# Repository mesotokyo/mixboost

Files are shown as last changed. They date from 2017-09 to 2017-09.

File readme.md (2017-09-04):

# MixBoost - Clean Booster & Loop Switcher & Send-Return mixer stompbox effector



## toggle mode by SW2

 * When SW2 is upper position, 'latch mode' - toggle ON/OFF by push SW1.
 * When SW2 is lower position, 'momentary mode' - ON while SW1 is pushed.

## toggle mode by SW3

 * When SW3 is lower position, 'booster mode'.
 * When SW3 is middle position, 'switch mode' - boosted signal is routed to 'send' and output is returned signal.
 * When SW3 is uppper position, 'mix mode' - boosted signal is routed to 'send', and output is returned signal mexed with input signal.

## jumper pins

 * Voltage source type can select by P1. +9V: uppper, +5V: lower (bypass 5V regulator).
 * When 'mix mode', mixed input signal can select by P2. non-boosted: lower, boosted: upper.

## component selectiong memo

 * recommend metal film resistor for R4, R5.
 * C4, C5, C15, C19 are non-polar electrolytic capacitors.
 * C6, C10 are electrolytic capacitors.
 * SW1 is momentary push switch - pay attention to orientation! pin 1 to left side.
 * SW2 is ON-ON toggle switch.
 * SW3 is ON-ON-ON toggle switch.
 * Q1, Q2 are 2N7000 MOSFET.
 * You can replace RV1 and RV2 to 10k.
 * D1 is BAT43.
 * recommend low noise OP-amp like 'NJM4580DD' for U2, 'NJM4580ND' for U4, U6.
 * You can replace U1 to R-78E5.
 * P3 is power inlet. GND is on right side.

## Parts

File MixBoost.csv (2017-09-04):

Reference | Value | Footprint | Datasheet
R8 | 1M | Resistors_SMD:R_0805_HandSoldering
R9 | 47k | Resistors_SMD:R_0805_HandSoldering
RV1 | 100k | Potentiometers:Potentiometer_WirePads
C1 | 0.1u | Capacitors_SMD:C_0805_HandSoldering
C9 | 0.1u | Capacitors_SMD:C_0805_HandSoldering
R5 | 10k | Resistors_SMD:R_0805_HandSoldering
R4 | 1k | Resistors_SMD:R_0805_HandSoldering
R3 | 47k | Resistors_SMD:R_0805_HandSoldering
C5 | 4.7u | Capacitors_ThroughHole:CP_Radial_D5.0mm_P2.00mm
R7 | 1k | Resistors_SMD:R_0805_HandSoldering
C14 | 0.1u | Capacitors_SMD:C_0805_HandSoldering
SW2 | LAT/MOM | switches:SPDT_switch
RV2 | 100k | pots:alpha_RV141F
R14 | 10k | Resistors_SMD:R_0805_HandSoldering
R17 | 10k | Resistors_SMD:R_0805_HandSoldering
R19 | 10k | Resistors_SMD:R_0805_HandSoldering
R24 | 10k | Resistors_SMD:R_0805_HandSoldering
SW3 | Switch_SPDT_x2 | switches:DPDT_switch
C2 | 0.33u | Capacitors_SMD:C_0805_HandSoldering
C3 | 0.1u | Capacitors_SMD:C_0805_HandSoldering
P3 | CONN_01X02 | Pin_Headers:Pin_Header_Straight_1x02_Pitch2.54mm
C10 | 10u | Capacitors_ThroughHole:CP_Radial_D5.0mm_P2.00mm
C6 | 10u | Capacitors_ThroughHole:CP_Radial_D5.0mm_P2.00mm
C11 | 0.1u | Capacitors_SMD:C_0805_HandSoldering
C7 | 0.1u | Capacitors_SMD:C_0805_HandSoldering
C8 | 0.1u | Capacitors_SMD:C_0805_HandSoldering
C12 | 0.1u | Capacitors_SMD:C_0805_HandSoldering
D1 | D_Schottky | Diodes_ThroughHole:D_DO-41_SOD81_P7.62mm_Horizontal
D2 | LED | LEDs:LED_D5.0mm
R21 | 1k | Resistors_SMD:R_0805_HandSoldering
U5 | TC7WH74 | Housings_SSOP:SSOP-8_2.95x2.8mm_Pitch0.65mm
C15 | 4.7u | Capacitors_ThroughHole:CP_Radial_D5.0mm_P2.00mm
R6 | 10k | Resistors_SMD:R_0805_HandSoldering
R20 | 10k | Resistors_SMD:R_0805_HandSoldering
R15 | 10k | Resistors_SMD:R_0805_HandSoldering
R16 | 47k | Resistors_SMD:R_0805_HandSoldering
C19 | 4.7u | Capacitors_ThroughHole:CP_Radial_D5.0mm_P2.00mm
R11 | 1M | Resistors_SMD:R_0805_HandSoldering
C17 | 1u | Capacitors_SMD:C_0805_HandSoldering
Q1 | Q_NMOS_SGD | TO_SOT_Packages_THT:TO-92_Molded_Narrow
R23 | 1k | Resistors_SMD:R_0805_HandSoldering
U7 | 4052 | Housings_SOIC:SOIC-16W_5.3x10.2mm_Pitch1.27mm
P1 | CONN_01X03 | Pin_Headers:Pin_Header_Straight_1x03_Pitch2.54mm
J1 | JACK_TRS_6PINS | jacks:NYS215
J2 | JACK_TRS_6PINS | jacks:NYS215
Q2 | Q_NMOS_SGD | TO_SOT_Packages_THT:TO-92_Molded_Narrow
D3 | LED | LEDs:LED_D3.0mm
R22 | 2k | Resistors_SMD:R_0805_HandSoldering
U3 | MAPU01-D | mau100:MAU100
SW1 | Switch_SPDT_x2 | switches:alpha-push_DPDT
C13 | 0.1u | Capacitors_SMD:C_0805_HandSoldering
C16 | 0.1u | Capacitors_SMD:C_0805_HandSoldering
R1 | 1M | Resistors_SMD:R_0805_HandSoldering
R2 | 47k | Resistors_SMD:R_0805_HandSoldering
C4 | 4.7u | Capacitors_ThroughHole:CP_Radial_D5.0mm_P2.00mm
P2 | CONN_01X03 | Pin_Headers:Pin_Header_Straight_1x03_Pitch2.54mm
R10 | 47k | Resistors_SMD:R_0805_HandSoldering
U2 | TL072 | Housings_DIP:DIP-8_W7.62mm_Socket
U6 | TL072 | JRC:DMP8
U4 | TL072 | JRC:DMP8
C18 | 0.1u | Capacitors_SMD:C_0805_HandSoldering
C20 | 0.1u | Capacitors_SMD:C_0805_HandSoldering
U1 | LM7805CT | Power_Integrations:TO-220
J3 | JACK_TRS_6PINS | jacks:NYS215

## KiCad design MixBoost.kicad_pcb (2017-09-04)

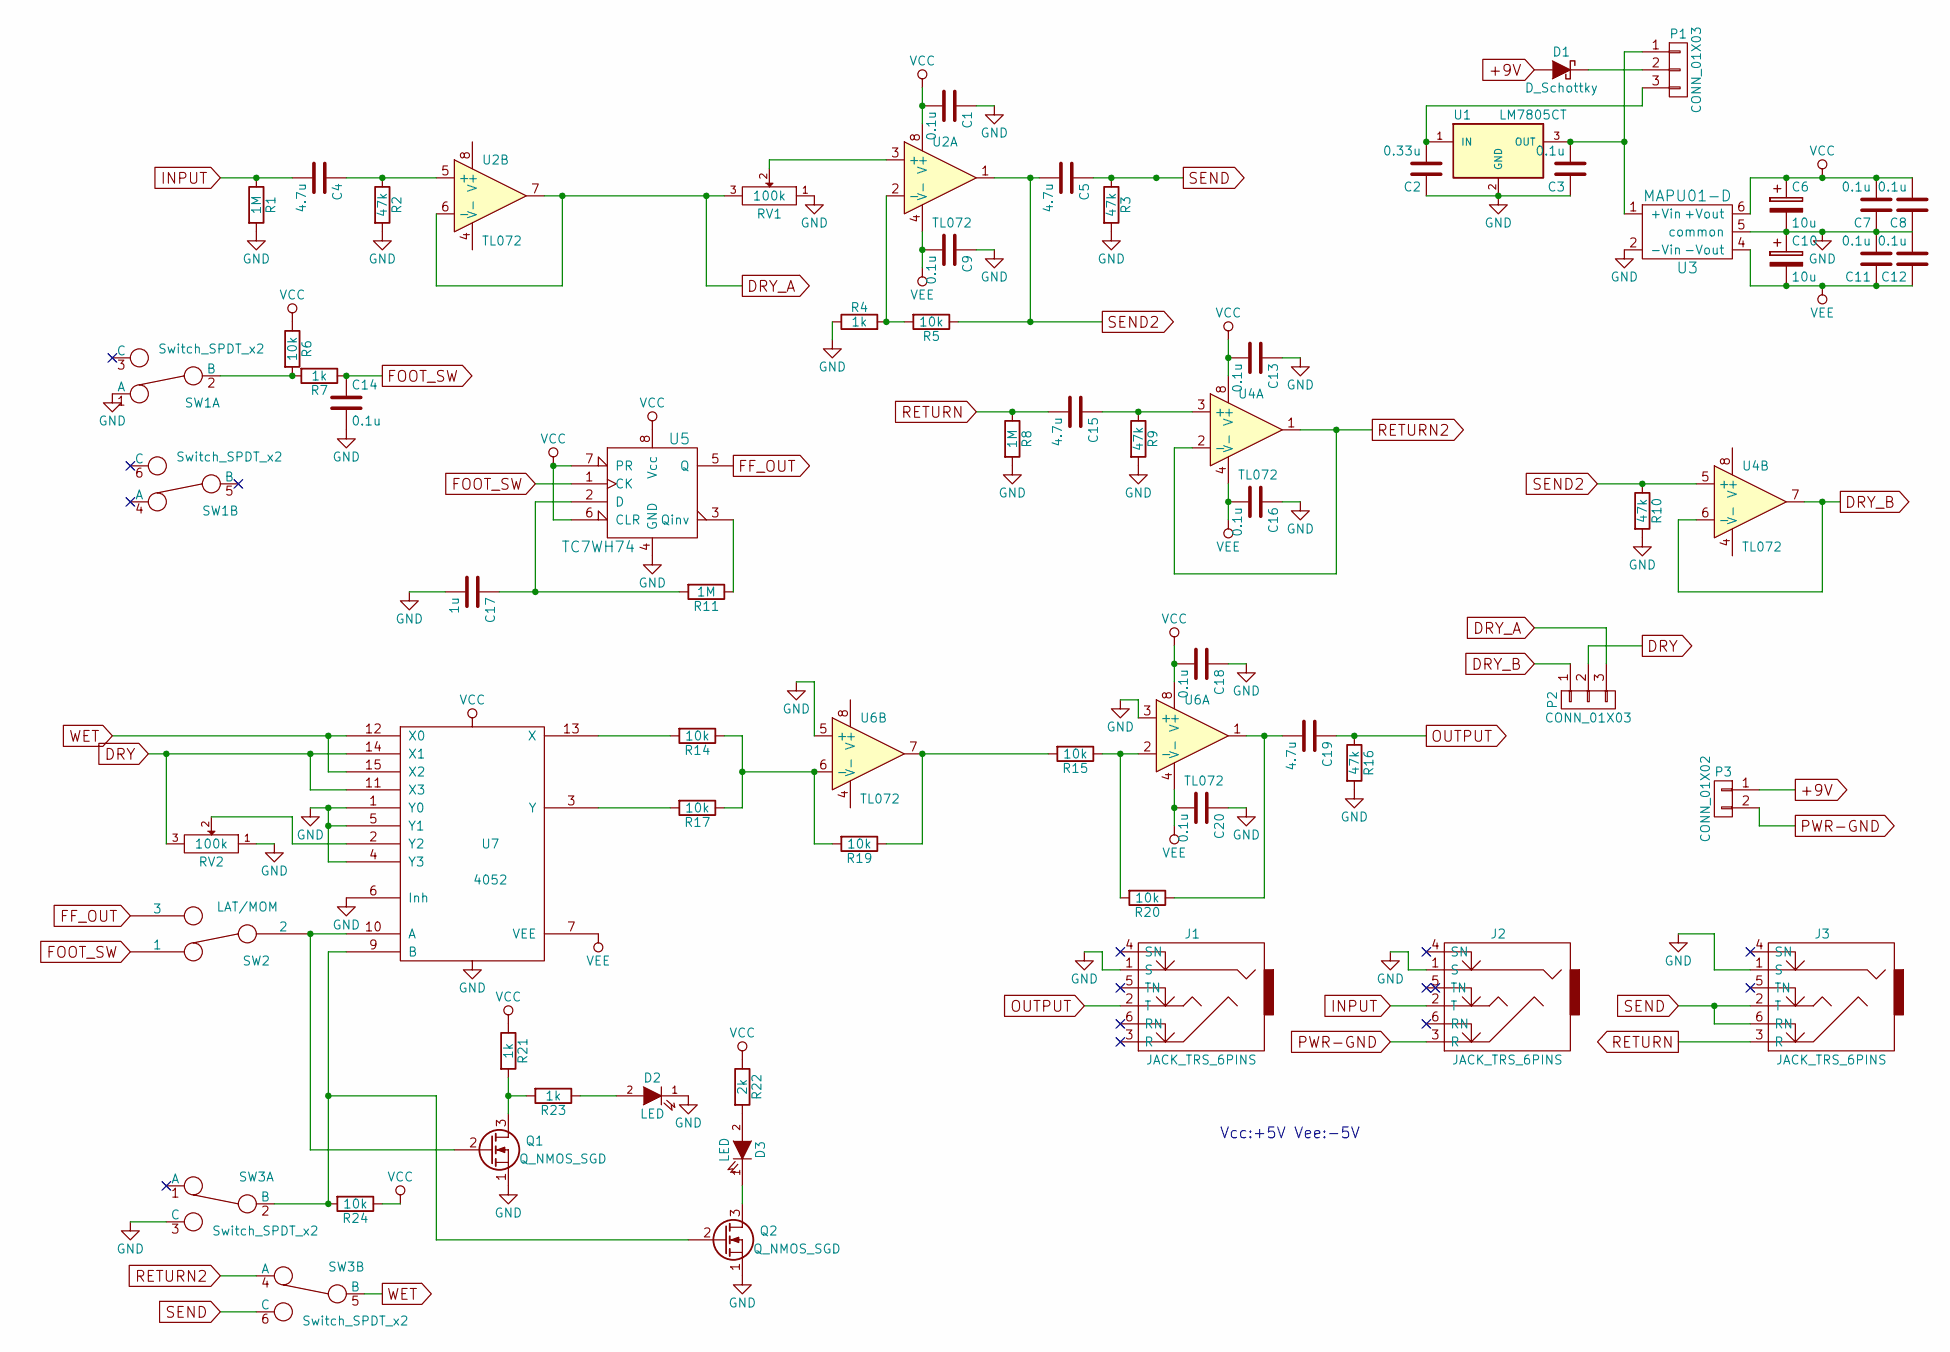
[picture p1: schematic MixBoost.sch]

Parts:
C1, C3, C7, C8, C9, C11, C12, C13, C14, C16, C18, C20: 0.1u; C_0805_HandSoldering
C2: 0.33u; C_0805_HandSoldering
C4, C5, C15, C19: 4.7u; CP_Radial_D5.0mm_P2.00mm
C6, C10: 10u; CP_Radial_D5.0mm_P2.00mm
C17: 1u; C_0805_HandSoldering
D1: D_Schottky; D_DO-41_SOD81_P7.62mm_Horizontal
D2: LED; LED_D5.0mm
D3: LED; LED_D3.0mm
J1, J2, J3: JACK_TRS_6PINS; NYS215
P1, P2: CONN_01X03; Pin_Header_Straight_1x03_Pitch2.54mm
P3: CONN_01X02; Pin_Header_Straight_1x02_Pitch2.54mm
Q1, Q2: Q_NMOS_SGD; TO-92_Molded_Narrow
R1, R8, R11: 1M; R_0805_HandSoldering
R2, R3, R9, R10, R16: 47k; R_0805_HandSoldering
R4, R7, R21, R23: 1k; R_0805_HandSoldering
R5, R6, R14, R15, R17, R19, R20, R24: 10k; R_0805_HandSoldering
R22: 2k; R_0805_HandSoldering
RV1: 100k; Potentiometer_WirePads
RV2: 100k; alpha_RV141F
SW1: Switch_SPDT_x2; alpha-push_DPDT
SW2: LAT/MOM; SPDT_switch
SW3: Switch_SPDT_x2; DPDT_switch
U1: LM7805CT; TO-220
U2: TL072; DIP-8_W7.62mm_Socket
U3: MAPU01-D; MAU100
U4, U6: TL072; DMP8
U5: TC7WH74; SSOP-8_2.95x2.8mm_Pitch0.65mm
U7: 4052; SOIC-16W_5.3x10.2mm_Pitch1.27mm

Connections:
+9V: D1.2 (A), P3.1
DRY: P2.2, RV2.3, U7.11 (X3), U7.14 (X1)
DRY_A: P2.3, RV1.3, U2.6 (-), U2.7
DRY_B: P2.1, U4.6 (-), U4.7
FF_OUT: SW2.3, U5.5 (Q)
FOOT_SW: C14.1, R7.1, SW2.1, U5.1 (CK)
GND: C1.1, C2.1, C3.1, C6.2, C7.1, C8.1, C9.1, C10.1, C11.2, C12.2, C13.1, C14.2, C16.1, C17.2, C18.1, C20.1, D2.1 (K), J1.1 (S), J2.1 (S), J3.1 (S), Q1.1 (S), Q2.1 (S), R1.2, R2.2, R3.2, R4.1, R8.2, R9.2, R10.2, R16.2, RV1.1, RV2.1, SW1.1 (A), SW3.3 (C), U1.2 (GND), U3.2 (-Vin), U3.5 (common), U5.4 (GND), U6.3 (+), U6.5 (+), U7.1 (Y0), U7.4 (Y3), U7.5 (Y1), U7.6 (Inh), U7.8 (VSS)
INPUT: C4.2, J2.2 (T), R1.1
unnamed: C2.2, P1.3, U1.1 (IN)
unnamed: C3.2, P1.1, U1.3 (OUT), U3.1 (+Vin)
unnamed: C4.1, R2.1, U2.5 (+)
unnamed: C15.1, R9.1, U4.3 (+)
unnamed: C17.1, R11.2, U5.2 (D)
unnamed: C19.2, R20.1, U6.1
unnamed: D1.1 (K), P1.2
unnamed: D2.2 (A), R23.1
unnamed: D3.1 (K), Q2.3 (D)
unnamed: D3.2 (A), R22.2
unnamed: Q1.2 (G), SW2.2, U7.10 (A)
unnamed: Q1.3 (D), R21.2, R23.2
unnamed: Q2.2 (G), R24.2, SW3.2 (B), U7.9 (B)
unnamed: R4.2, R5.2, U2.2 (-)
unnamed: R6.2, R7.2, SW1.2 (B)
unnamed: R11.1, U5.3 (Qinv)
unnamed: R14.1, R17.1, R19.2, U6.6 (-)
unnamed: R14.2, U7.13 (X)
unnamed: R15.1, R20.2, U6.2 (-)
unnamed: R15.2, R19.1, U6.7
unnamed: R17.2, U7.3 (Y)
unnamed: RV1.2, U2.3 (+)
unnamed: RV2.2, U7.2 (Y2)
OUTPUT: C19.1, J1.2 (T), R16.1
PWR-GND: J2.3 (R), P3.2
RETURN: C15.2, J3.3 (R), R8.1
RETURN2: SW3.4 (A), U4.1, U4.2 (-)
SEND: C5.1, J3.2 (T), J3.6 (RN), R3.1, SW3.6 (C)
SEND2: C5.2, R5.1, R10.1, U2.1, U4.5 (+)
VCC: C1.2, C6.1, C7.2, C8.2, C13.2, C18.2, R6.1, R21.1, R22.1, R24.1, U2.8 (V+), U3.6 (+Vout), U4.8 (V+), U5.6 (CLR), U5.7 (PR), U5.8 (Vcc), U6.8 (V+), U7.16 (VDD)
VEE: C9.2, C10.2, C11.1, C12.1, C16.2, C20.2, U2.4 (V-), U3.4 (-Vout), U4.4 (V-), U6.4 (V-), U7.7 (VEE)
WET: SW3.5 (B), U7.12 (X0), U7.15 (X2)

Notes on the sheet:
Vcc:+5V Vee:-5V

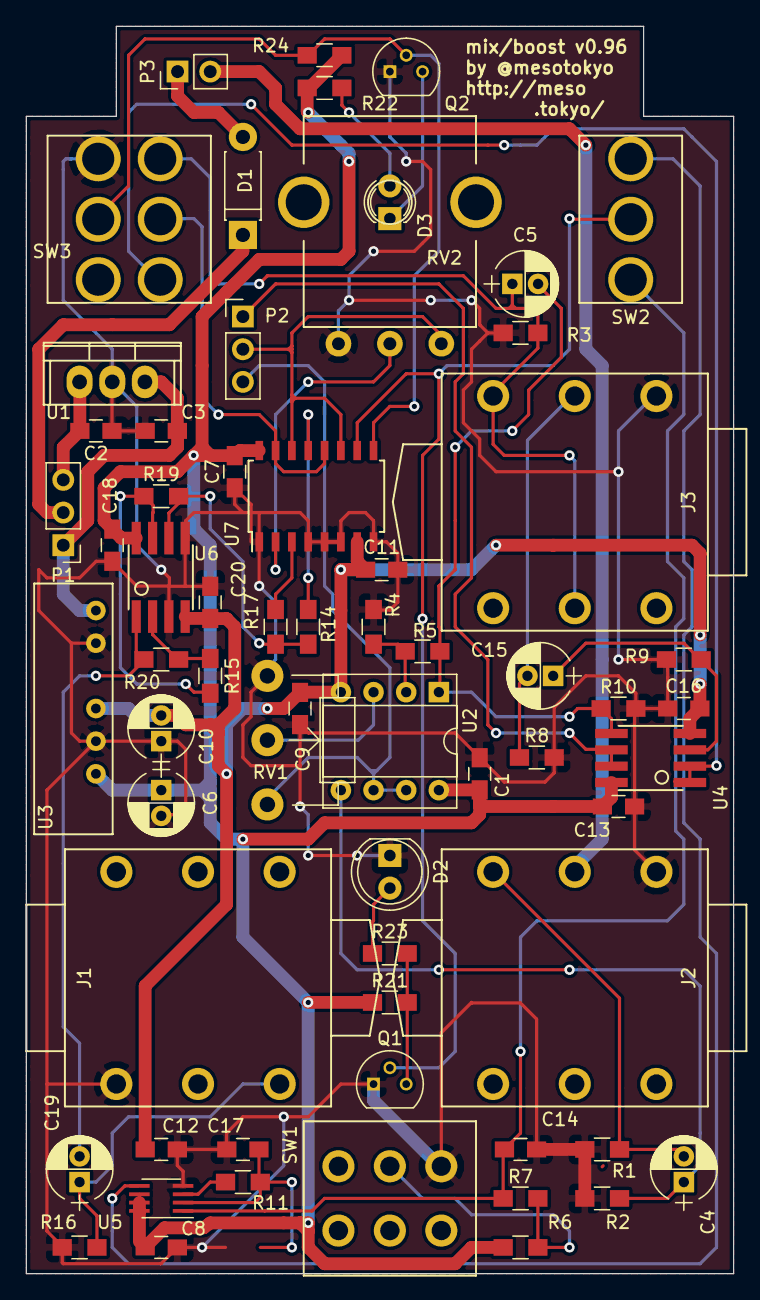
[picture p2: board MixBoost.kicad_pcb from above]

Board: 2 copper layers, 55.0 x 97.0 mm, 64 parts (0 on the bottom side), 40 nets.

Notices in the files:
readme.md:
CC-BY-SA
